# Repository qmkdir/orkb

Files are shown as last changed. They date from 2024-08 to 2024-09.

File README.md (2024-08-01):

> [!CAUTION]
> PCB in active development, don't manufacture until files are released!

# ORCA KEYBOARD

ORCA is a 46 key column-staggered split keyboard with an aggresive stagger (especially the pinky) and a curved thumb cluster with an extra index finger key!

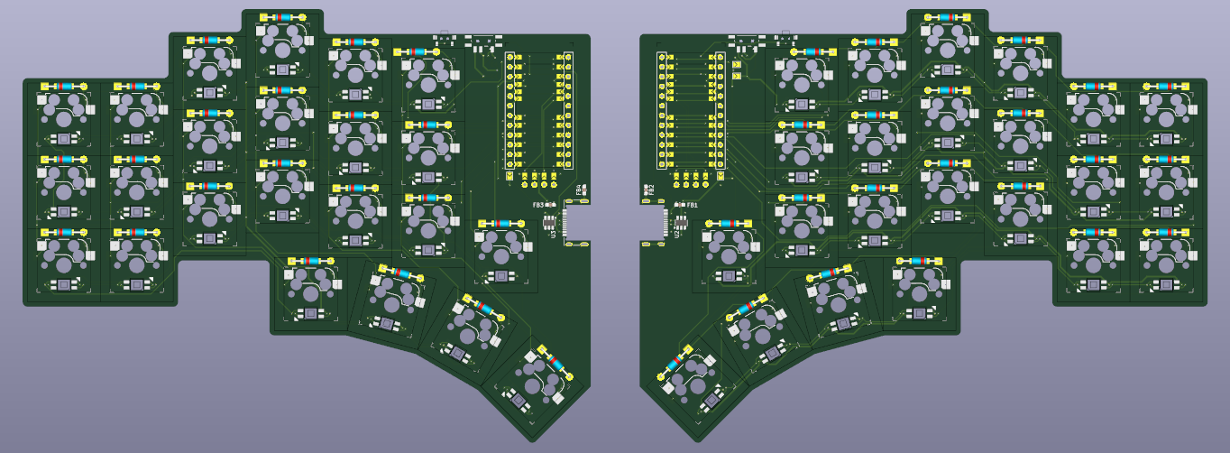
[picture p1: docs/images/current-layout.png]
ORCA layout


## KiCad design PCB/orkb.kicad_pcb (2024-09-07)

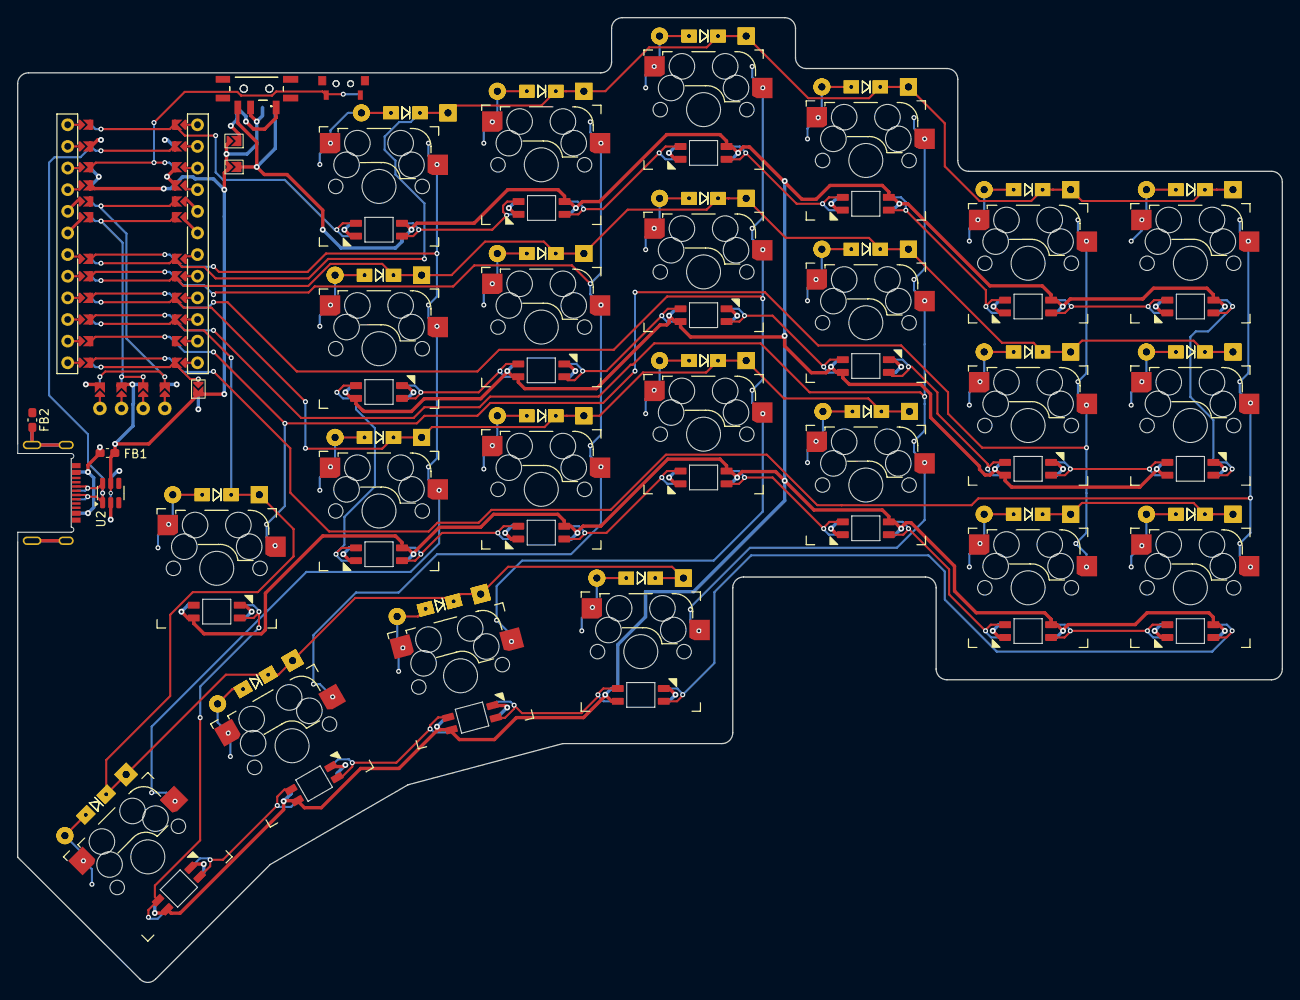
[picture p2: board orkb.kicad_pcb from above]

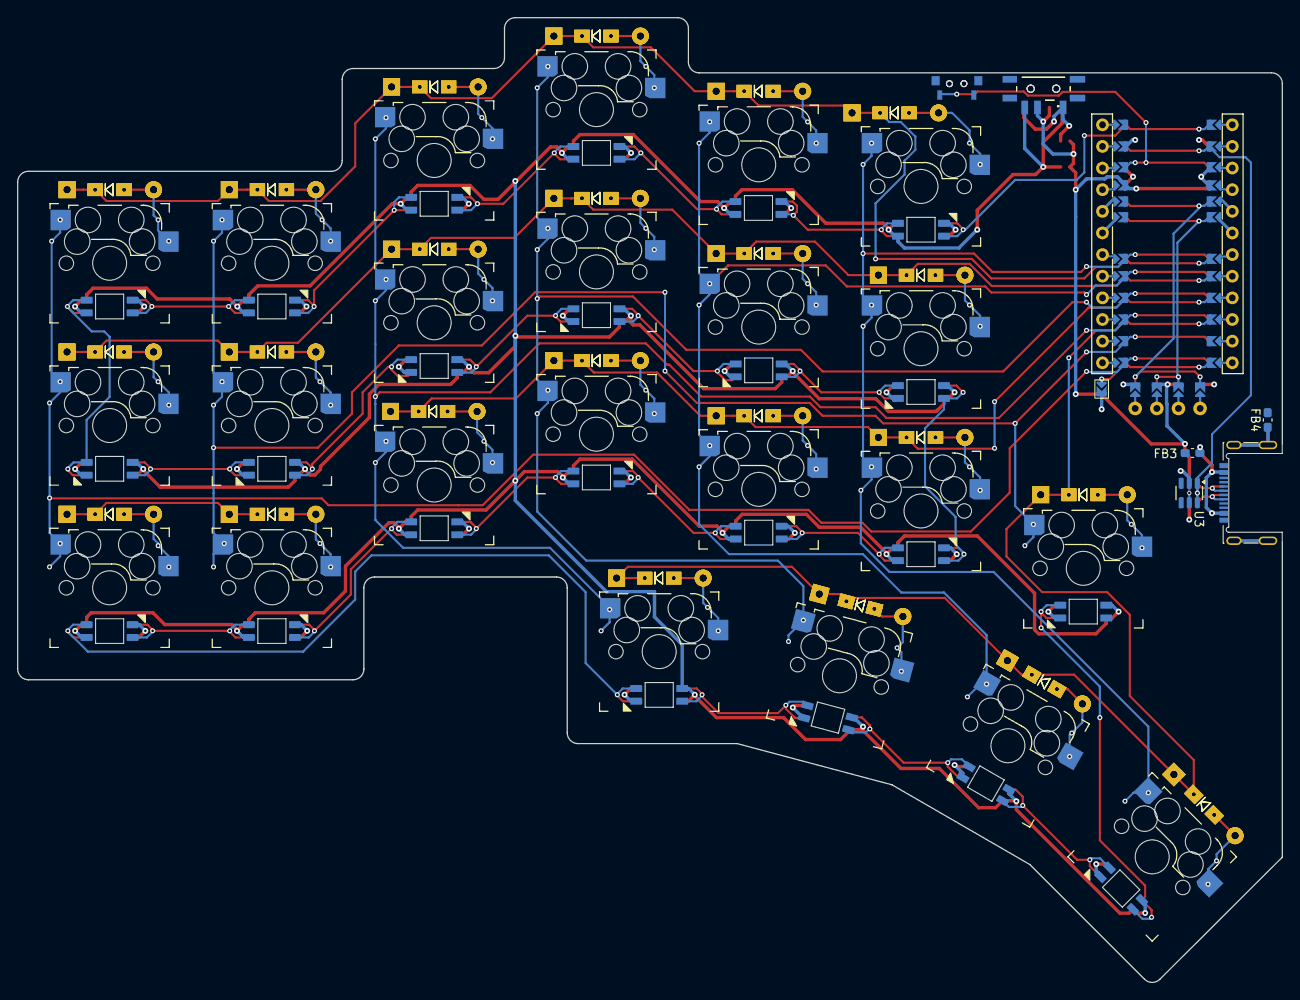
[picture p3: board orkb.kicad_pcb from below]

Board: 2 copper layers, 148.5 x 113.3 mm, 109 parts (61 on the bottom side), 67 nets.

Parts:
D1, D2, D3, D4, D5, D6, D7, D8, D9, D10, D11, D12, D13, D14, D15, D16, D17, D18, D19, D20, D21, D22, D23, D24, D25, D26, D27, D28, D29, D30, D31, D32, D33, D34, D35, D36, D37, D38, D39, D40, D41, D42, D43, D44, D45, D46: 1N4841/1N4148W; Diode_DO35_SOD123_Hybrid
FB1, FB2, FB3, FB4: FerriteBead; C_0603_1608Metric_Pad1.08x0.95mm_HandSolder
J1: USB_C_Receptacle_USB2.0; HRO-TYPE-C-31-M-13x_DOUBLESIDED_Molex-216990_GCT-USB45xx
JP1, JP2, JP3, JP4: Jumper_2_Open; Jumper_min_v2
LED1, LED2, LED3, LED4, LED5, LED6, LED7, LED8, LED9, LED10, LED11, LED12, LED13, LED14, LED15, LED16, LED17, LED18, LED19, LED20, LED21, LED22, LED23: SK6803MINI-E; MX_SK6812MINI-E_REVERSIBLE
P1: OLED; SSD1306-0.91-OLED-4pin-128x32_DOUBLESIDED
RES1, RES2: TS-A002_TactileSW; YTS-A002
SW1, SW2, SW3, SW4, SW5, SW6, SW7, SW8, SW9, SW10, SW11, SW12, SW13, SW14, SW15, SW16, SW17, SW18, SW19, SW20, SW21, SW22, SW23: MXHS; SW_MX_HotSwap_Reversible
SW24, SW25: MSK12C02
U1: ProMicro; ProMicro_Jumpers_V2
U2, U3: SRV05-4; SOT-23-6

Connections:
/PWR_GLOW: JP3.1 (A), SW24.NC, SW25.NC
/PWR_KEY: JP4.1 (A), LED1.1 (VDD), LED2.1 (VDD), LED3.1 (VDD), LED4.1 (VDD), LED5.1 (VDD), LED6.1 (VDD), LED7.1 (VDD), LED8.1 (VDD), LED9.1 (VDD), LED10.1 (VDD), LED11.1 (VDD), LED12.1 (VDD), LED13.1 (VDD), LED14.1 (VDD), LED15.1 (VDD), LED16.1 (VDD), LED17.1 (VDD), LED18.1 (VDD), LED19.1 (VDD), LED20.1 (VDD), LED21.1 (VDD), LED22.1 (VDD), LED23.1 (VDD), SW24.NO, SW25.NO
/VCC_LINK: FB1.1, FB3.1, J1.A4 (VBUS), J1.A9 (VBUS), J1.B4 (VBUS), J1.B9 (VBUS)
DATA: J1.A7 (D-), J1.B7 (D-), U1.2 (RX1/PD2), U2.1 (IO1), U2.6 (IO4), U3.1 (IO1), U3.6 (IO4)
GND: FB2.2, FB4.2, J1.A1 (GND), J1.A12 (GND), J1.B1 (GND), J1.B12 (GND), JP2.1 (A), LED1.3 (GND), LED2.3 (GND), LED3.3 (GND), LED4.3 (GND), LED5.3 (GND), LED6.3 (GND), LED7.3 (GND), LED8.3 (GND), LED9.3 (GND), LED10.3 (GND), LED11.3 (GND), LED12.3 (GND), LED13.3 (GND), LED14.3 (GND), LED15.3 (GND), LED16.3 (GND), LED17.3 (GND), LED18.3 (GND), LED19.3 (GND), LED20.3 (GND), LED21.3 (GND), LED22.3 (GND), LED23.3 (GND), P1.1 (GND), RES1.2, RES1.3, RES2.2, RES2.3, SW24.MP (GND), SW25.MP (GND), U1.3 (GND), U1.4 (GND), U1.23 (GND), U2.2 (VN), U3.2 (VN)
Hand: JP1.2 (B), JP2.2 (B), U1.12 (9/PB5)
LED: LED1.4 (DIN), U1.1 (TX0/PD3)
unnamed: D1.2 (A), D23.2 (A), SW1.2
unnamed: D2.2 (A), D24.2 (A), SW2.2
unnamed: D10.2 (A), D32.2 (A), SW10.2
unnamed: D11.2 (A), D33.2 (A), SW11.2
unnamed: D12.2 (A), D34.2 (A), SW12.2
unnamed: D13.2 (A), D35.2 (A), SW13.2
unnamed: D14.2 (A), D36.2 (A), SW14.2
unnamed: D15.2 (A), D37.2 (A), SW15.2
unnamed: D16.2 (A), D38.2 (A), SW16.2
unnamed: D17.2 (A), D39.2 (A), SW17.2
unnamed: D18.2 (A), D40.2 (A), SW18.2
unnamed: D19.2 (A), D41.2 (A), SW19.2
unnamed: D20.2 (A), D42.2 (A), SW20.2
unnamed: D21.2 (A), D43.2 (A), SW21.2
unnamed: D22.2 (A), D44.2 (A), SW22.2
unnamed: D3.2 (A), D25.2 (A), SW3.2
unnamed: D4.2 (A), D26.2 (A), SW4.2
unnamed: D5.2 (A), D27.2 (A), SW5.2
unnamed: D6.2 (A), D28.2 (A), SW6.2
unnamed: D7.2 (A), D29.2 (A), SW7.2
unnamed: D8.2 (A), D30.2 (A), SW8.2
unnamed: D9.2 (A), D31.2 (A), SW9.2
unnamed: D45.2 (A), D46.2 (A), SW23.2
unnamed: FB2.1, FB4.1, J1.S1 (SHIELD)
unnamed: LED1.2 (DOUT), LED2.4 (DIN)
unnamed: LED2.2 (DOUT), LED3.4 (DIN)
unnamed: LED3.2 (DOUT), LED4.4 (DIN)
unnamed: LED4.2 (DOUT), LED5.4 (DIN)
unnamed: LED5.2 (DOUT), LED6.4 (DIN)
unnamed: LED7.4 (DIN), LED8.2 (DOUT)
unnamed: LED8.4 (DIN), LED9.2 (DOUT)
unnamed: LED10.4 (DIN), LED11.2 (DOUT)
unnamed: LED9.4 (DIN), LED10.2 (DOUT)
unnamed: LED11.4 (DIN), LED12.2 (DOUT)
unnamed: LED6.2 (DOUT), LED12.4 (DIN)
unnamed: LED7.2 (DOUT), LED13.4 (DIN)
unnamed: LED13.2 (DOUT), LED14.4 (DIN)
unnamed: LED14.2 (DOUT), LED15.4 (DIN)
unnamed: LED15.2 (DOUT), LED16.4 (DIN)
unnamed: LED16.2 (DOUT), LED17.4 (DIN)
unnamed: LED17.2 (DOUT), LED18.4 (DIN)
unnamed: LED18.2 (DOUT), LED23.4 (DIN)
unnamed: LED19.4 (DIN), LED20.2 (DOUT)
unnamed: LED20.4 (DIN), LED21.2 (DOUT)
unnamed: LED21.4 (DIN), LED22.2 (DOUT)
unnamed: LED22.4 (DIN), LED23.2 (DOUT)
RESET: RES1.1, RES2.1, U1.22 (RST)
SCL: P1.3 (SCL), U1.6 (3/PD0)
SDA: P1.4 (SDA), U1.5 (2/PD1)
VCC: FB1.2, FB3.2, JP1.1 (A), JP3.2 (B), JP4.2 (B), P1.2 (VCC), SW24.COM, SW25.COM, U1.21 (VCC), U2.5 (VP), U3.5 (VP)
col0: SW1.1, SW7.1, SW13.1, SW19.1, U1.18 (A1/PF6)
col1: SW2.1, SW8.1, SW14.1, SW20.1, U1.17 (A0/PF7)
col2: SW3.1, SW9.1, SW15.1, SW21.1, U1.16 (15/PB1)
col3: SW4.1, SW10.1, SW16.1, SW22.1, U1.15 (14/PB3)
col4: SW5.1, SW11.1, SW17.1, SW23.1, U1.14 (16/PB2)
col5: SW6.1, SW12.1, SW18.1, U1.13 (10/PB6)
row0: D1.1 (K), D2.1 (K), D3.1 (K), D4.1 (K), D5.1 (K), D6.1 (K), D23.1 (K), D24.1 (K), D25.1 (K), D26.1 (K), D27.1 (K), D28.1 (K), U1.7 (4/PD4)
row1: D7.1 (K), D8.1 (K), D9.1 (K), D10.1 (K), D11.1 (K), D12.1 (K), D29.1 (K), D30.1 (K), D31.1 (K), D32.1 (K), D33.1 (K), D34.1 (K), U1.8 (5/PC6)
row2: D13.1 (K), D14.1 (K), D15.1 (K), D16.1 (K), D17.1 (K), D18.1 (K), D35.1 (K), D36.1 (K), D37.1 (K), D38.1 (K), D39.1 (K), D40.1 (K), U1.9 (6/PD7)
row3: D19.1 (K), D20.1 (K), D21.1 (K), D22.1 (K), D41.1 (K), D42.1 (K), D43.1 (K), D44.1 (K), D45.1 (K), D46.1 (K), U1.10 (7/PE6)

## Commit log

2024-07-07 init
    Initial commit
    [orkb.kicad_pcb, orkb.kicad_sch]
2024-07-08 Added MCU with reverse routing
    MCU routed for reverse PCB usage
    TODO:
    Fix GND and RESET pin connections
    [orkb.kicad_pcb, orkb.kicad_sch]
2024-07-12 Draft schematic components
    [Pending]
    Import to PCB
    [orkb.kicad_pcb, orkb.kicad_sch]
2024-07-12 Keyboard layout and switch positioning
    [orkb.kicad_pcb, orkb.kicad_sch]
2024-07-12 Keyboard layout + component placement
    [orkb.kicad_pcb]
2024-07-15 First draft of routing of rows and columns
    [orkb.kicad_pcb]
2024-07-23 Refactoring entire project
    [orkb.kicad_pcb, orkb.kicad_sch]
2024-07-23 Added extra index finger switch
    [orkb.kicad_pcb, orkb.kicad_sch]
2024-07-23 Updating layout
    [orkb.kicad_pcb]
2024-07-23 Reset switch repositioning and labeling
    [orkb.kicad_pcb]
2024-07-24 Changing layout and adding space for a three way switch
    [orkb.kicad_pcb]
2024-07-24 Added support for LED in schematic
    [orkb.kicad_sch]
2024-07-24 Updated PCB with LED and switch
    [orkb.kicad_pcb, orkb.kicad_sch]
2024-07-25 Added underglow LED to schematic
    [orkb.kicad_pcb, orkb.kicad_sch]
2024-07-25 Added underglow LEDs to PCB
    [orkb.kicad_pcb, orkb.kicad_sch]
2024-07-26 LED double-sided routing for row0
    [orkb.kicad_pcb]
2024-07-26 Added all LED reversible connections
    [orkb.kicad_pcb]
2024-07-29 Initial column routing
    [orkb.kicad_pcb]
2024-07-30 Rows and columns routed
    [orkb.kicad_pcb]
2024-07-30 Row0 per key and under-glow RGB routing
    [orkb.kicad_pcb]
2024-07-31 Removing under-glow LEDs (for now)
    [orkb.kicad_pcb, orkb.kicad_sch]
2024-07-31 Per key RBG, Switch column and row routing complete
    [orkb.kicad_pcb, orkb.kicad_sch]
2024-07-31 Corrected schematic connection of index & thumb cluster
    [orkb.kicad_sch]
2024-07-31 Initial complete routing of PCB
    [orkb.kicad_pcb, orkb.kicad_sch]
2024-07-31 Fixing column order and routing
    [orkb.kicad_pcb, orkb.kicad_sch]
2024-08-01 Fix column routing for index/thumb cluster
    [orkb.kicad_pcb, orkb.kicad_sch]
2024-08-01 Updating README and PCB image
2024-08-01 Routing changes
    [orkb.kicad_pcb]
